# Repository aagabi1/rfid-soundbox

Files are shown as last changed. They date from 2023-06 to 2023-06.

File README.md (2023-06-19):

# rfid-soundbox
This is a modular prototype designed to mimick the famous gramophone using rfid technology - similar to the speaker system from the Ikea Frekvens collection (https://www.ikea.com/us/en/files/pdf/27/28/27281cda/frekvens_pr_kit.pdf).
Check out the rfid soundbox documentation pdf for a more detailed description.

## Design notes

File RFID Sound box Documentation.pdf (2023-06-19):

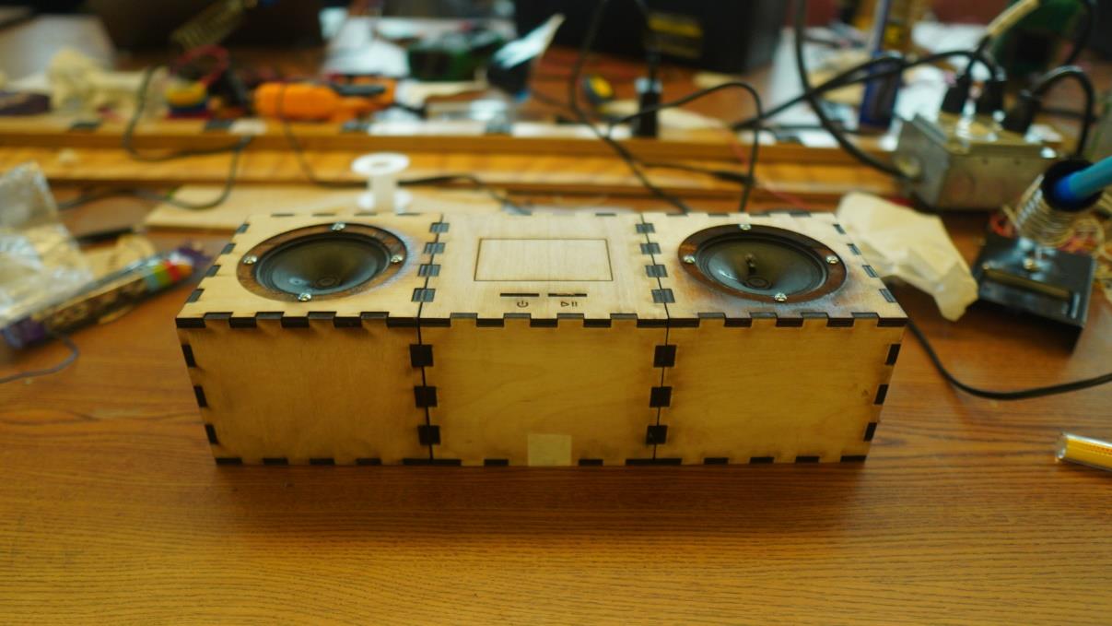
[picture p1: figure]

RFID Sound box Documentation

Courage Agabi

Section A

Part 1 – Hardware components

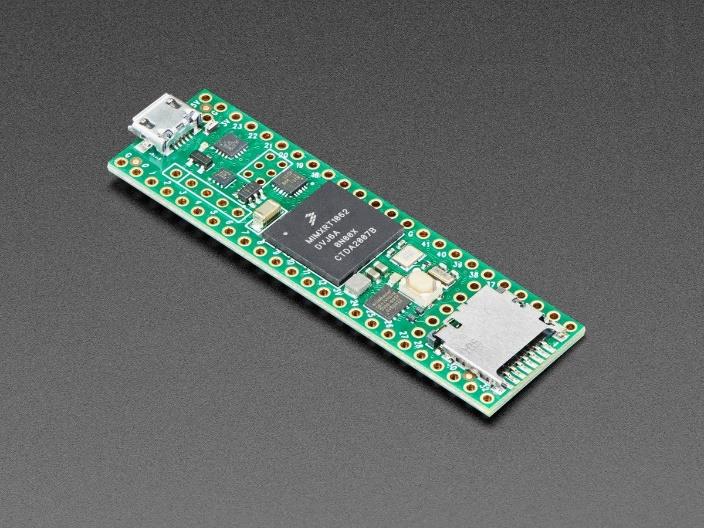
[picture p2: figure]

Teensy 4.1

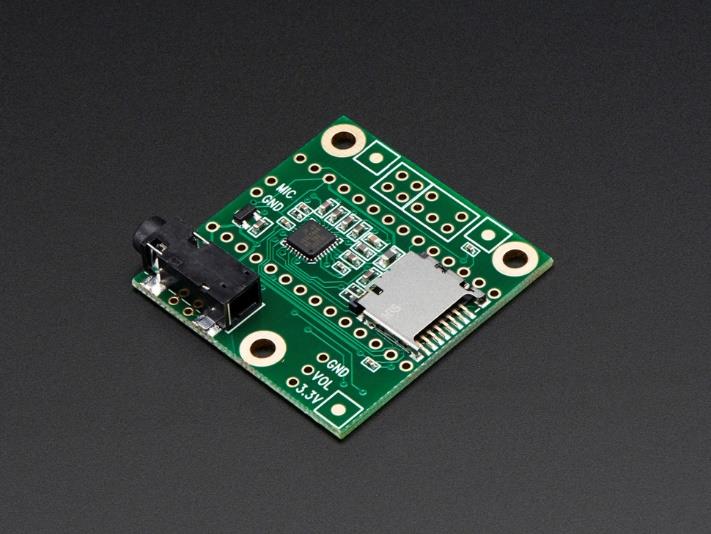
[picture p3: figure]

Teensy 16bit audio shield

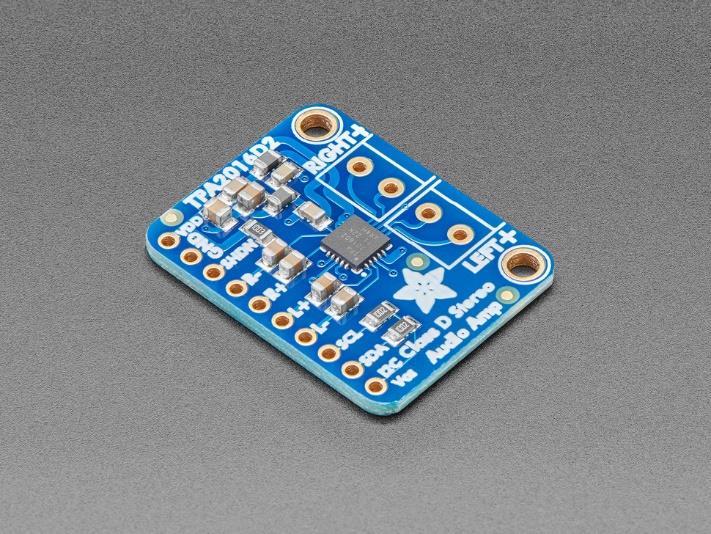
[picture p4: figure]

Adafruit 2.8W amplifier

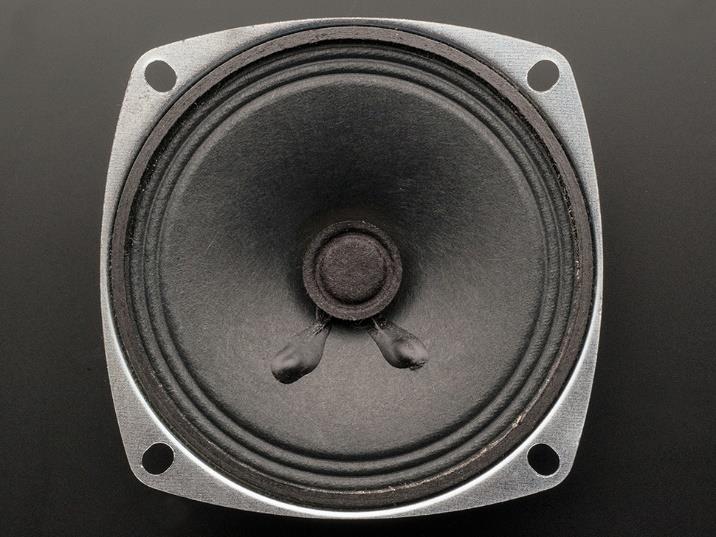
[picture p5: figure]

3W 4-ohm impedance speakers

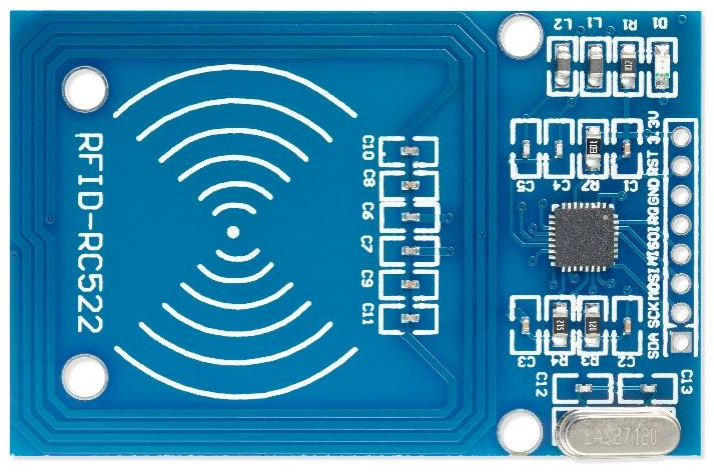
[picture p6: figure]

RFID reader

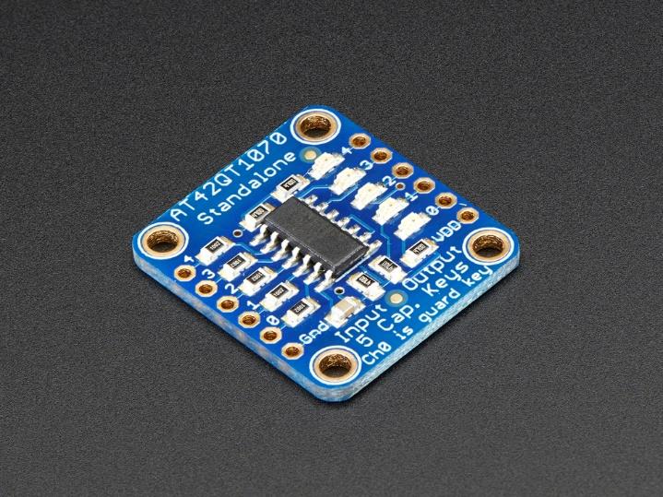
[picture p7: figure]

Capacitive touch sensor

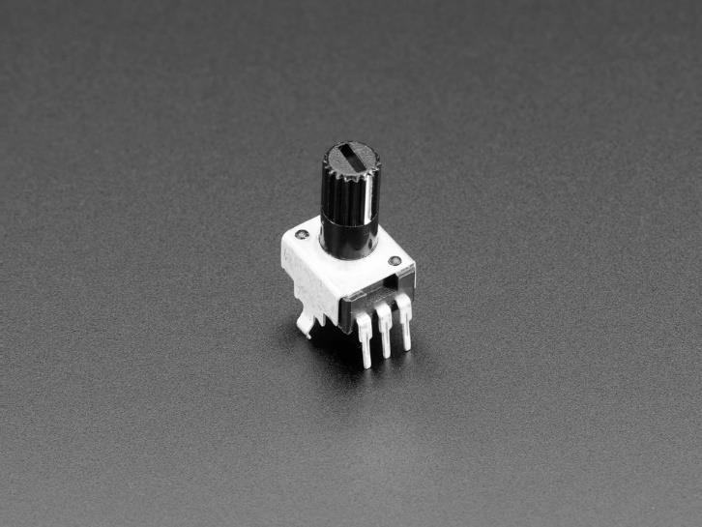
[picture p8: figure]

10k potentiometer

Part 2 – Libraries

MFRC512 library for RFID functionality (https://github.com/miguelbalboa/rfid.git)

TPA2016 for controlling amplifier (https://github.com/adafruit/Adafruit-TPA2016-Library.git)

Teensy audio library for controlling sgtl5000 chip in audio shield (https://www.pjrc.com/teensy/gui/)

Bounce library for touch input debouncing (https://github.com/thomasfredericks/Bounce2.git)

Wire library for I2C and SPI library for RFID reader

Part 3 – Custom components

RFID read and write

The MFRC library had functions to read and write hex values to a card but I needed to specify what part of the tag the data was written into and also add delimiters to know where to start and stop reading. I also needed to automatically convert the file name into hex and back into text when read. It would have been possible to do all this with the given functions but using this custom approach gave me a better understanding of the RFID tag system and how it can be used for projects that require higher encryption. It also helped with debugging read/write issues.

Audio amp node for volume control

The sgtl5000 chip allows you to change the voltage levels for the line out outputs. However, the result is a discrete step in volume change. I wanted continuous, smooth transitions in volume so I added an audio amplifier between the SD card wav node and the audio shield I2S node (see image below)

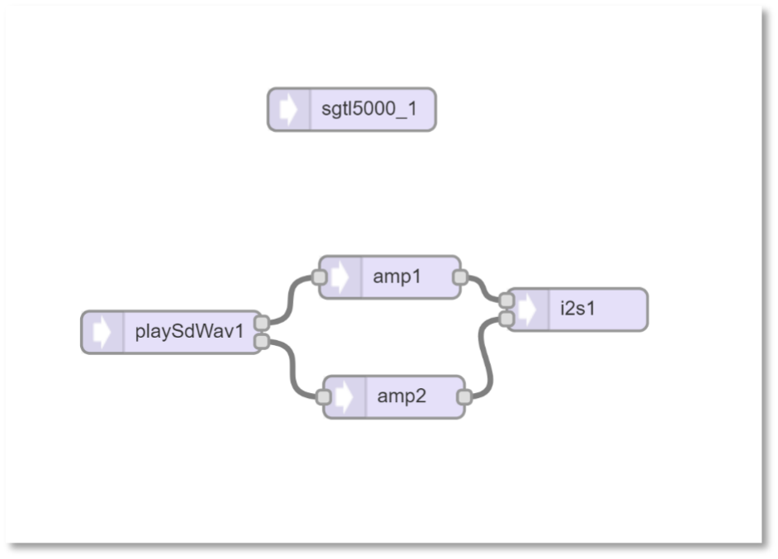
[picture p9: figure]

Figure 1. Sample audio configuration from PJRC graphic interface.

Hardware mounts

Finally, I designed hardware mounts for the audio shield, amplifier and power source. I did not want to glue these pieces to the plywood in case I needed them for other projects so I 3D printed these plates with side rails to hold the components. There are also notches on the side of the rails so that rubber bands can be wrapped around and placed in the notches. Lastly, the plates have extruding legs underneath that insert into holes in the plywood.

Part 4 – Skill learned

RFID data manipulation

I learned more about RFID tags than I care to admit. I learned potential ways to create more secure RFID tags such that it would be a reliable option for a household door locking system. Basically, you can change the key that the RFID tags have by default. The key is what you need to read data off the card. All tags have a default key but if you have a custom key it would be harder to use any key to open a door lock. And combined with the actual data on the key, the number of possible combinations increases exponentially (although there are still ways to get around this if you have unrestricted access to a person’s key).

3D printing best practices

I learned that when trying to fit or mount 3D printed pieces together, it is best to make more generic designs rather that hyper specific designs since the degree of accuracy of the 3D print is not always perfect. So, rather than have prongs sticking out from a 3D printed plate that fit specific mounting holes on a circuit board, you can just print rails that hold on to the board from the sides.

Part 5 – Iterative process

There were many moving parts in the assignment, so I worked on incremental features…

1. Getting the RFID to read and write the file name – this was fairly easy given that there is existing code to do this. I just had to understand where the data was being written and in what format
2. Getting the audio shield to play the song – this was a bit more difficult because of a few unknown bugs. The filename had to be in 8.3 format (excluding the directory) and it had to be all capital letters. So, for a song like “Stevie Wonder – Sir Duke” in the folder called “Stevie”, the data on the tag would be “STEVIE/SIRDUKE.WAV”. It was little things like this that made play back hard at first.
3. Once the tag had the right file format and the audio shield could read that file from the SD card, then the audio would play from the headphone jack
4. Getting the touch input – the capacitive touch sensor was also tricky because unbeknownst to me, it did some super quick calibration when power was turned on so the range would differ every time. However, getting it to work was straightforward with the Bounce library. The audio shield also had an updated play and pause method that was added recently so that made playback control easier.
5. Finally, I had to get the amp and speakers connected. The issue was with the wiring of the amp and potential ground loop which cause a lot of noise in the music. I fixed this issue by giving the amp and independent ground reference from the rest of the components (audio shield LR outputs and ground connections). Also, the design of the speakers was modular so the amp would struggle with properly powering the speakers if they were attached at different times. I have not found a fix or done enough testing to figure this part out

Ideas that didn’t pan out…

1. Connecting to Spotify – the audio amplifier issue was such a big problem for me that I was more focused on getting the best sound out of the speakers before adding the extra functionality. Also, the internet requirement would have meant that I had to buy another board (ESP-32) to connect the Teensy to Wi-Fi which would have been more expensive
2. Adjusting playback – I wanted to be able to rewind a song or just have all the songs play on shuffle but there was no straightforward way to adjust playback and I didn’t have time to implement the latter
3. Low power mode – The teensy has an option for low power mode where it basically shuts off when you connect the power ON/OFF pin to ground. I wanted to implement this with a transistor such that current flowed when the capacitive touch input drove the base high. I wasn’t sure if this would work and I didn’t want to try anything that might damage the Teensy so I just manually shut down the power supply.

Part 6 – Lessons learned

1. The most important lesson is probably that when working with audio, you have to make sure that you ground pins are properly connected to avoid audible noise problems. I thing a soldering solution would have been better and I think I should have started with just the amplifier and speaker and the DAC on the teensy before introducing the audio shield and the multiple ground connections.
2. When 3D printing, leave room for error and design more generally so that all the measurements don’t have to be ultra-specific for the piece to fit

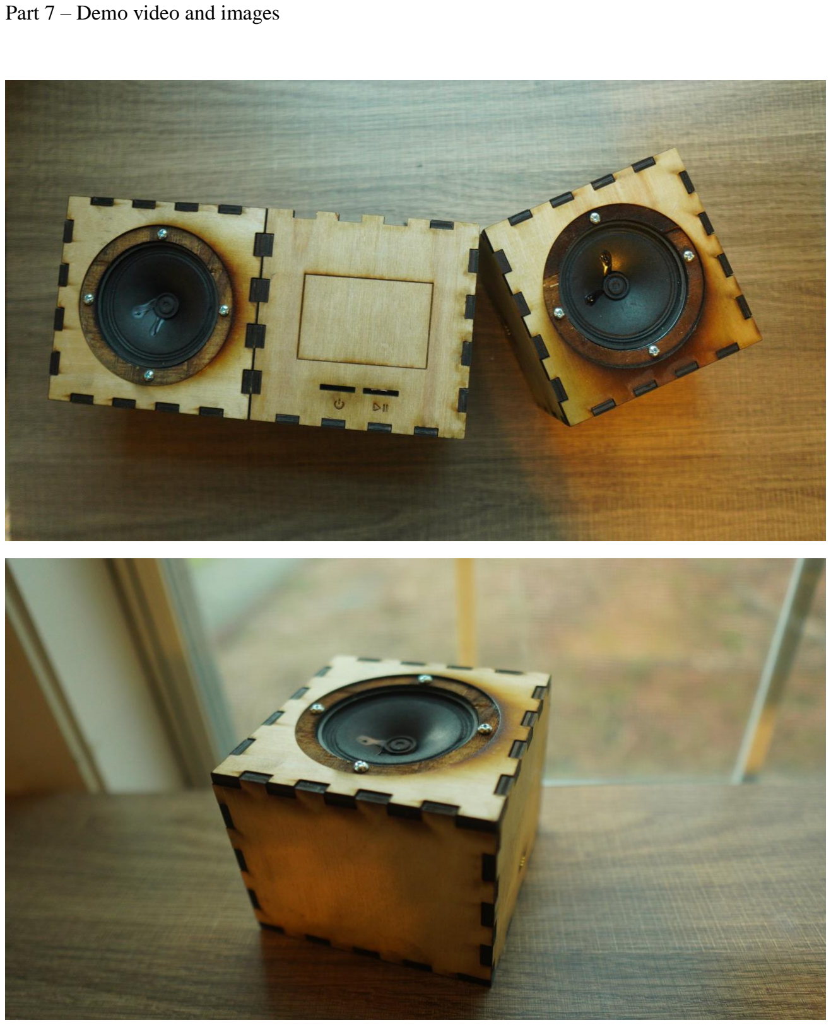
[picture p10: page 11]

Part 7 – Demo video and images

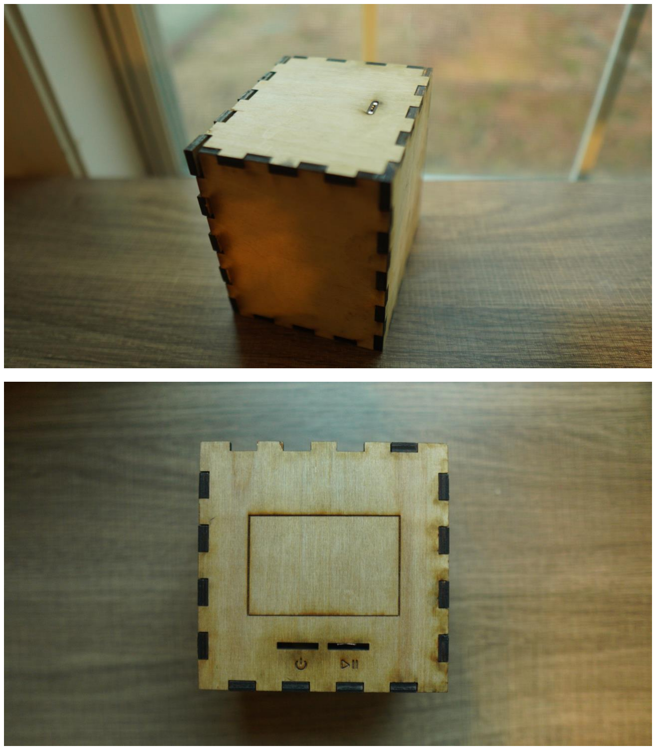
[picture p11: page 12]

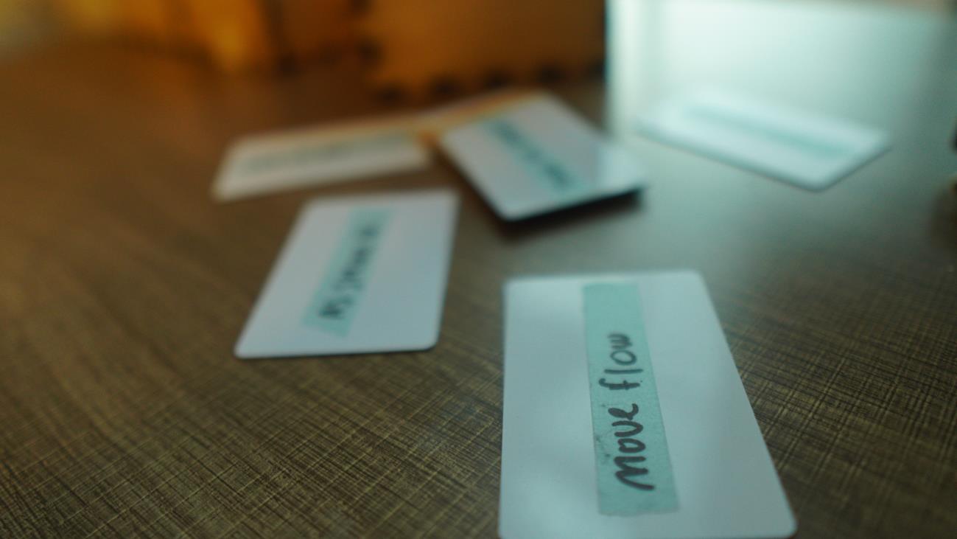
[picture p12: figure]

** see zip file for demo video

Part 8 – Code

**check zip folder for .cpp files (under the src folder)

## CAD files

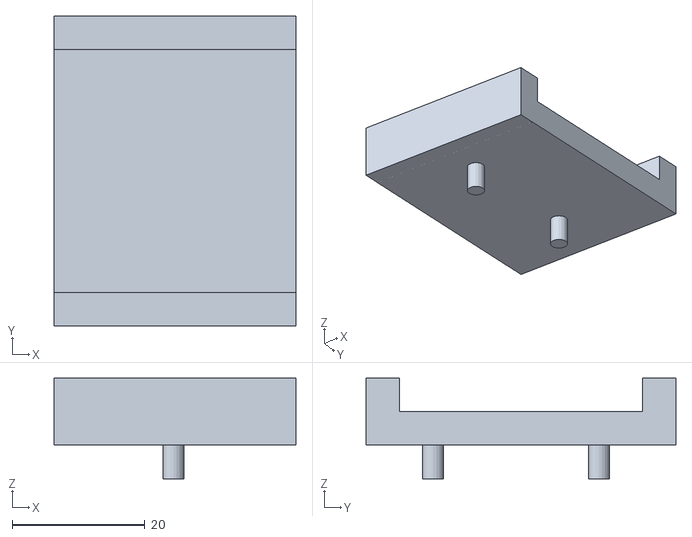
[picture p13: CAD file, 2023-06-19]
build/audio_shield.stl
36.5 x 46.7 x 15.2

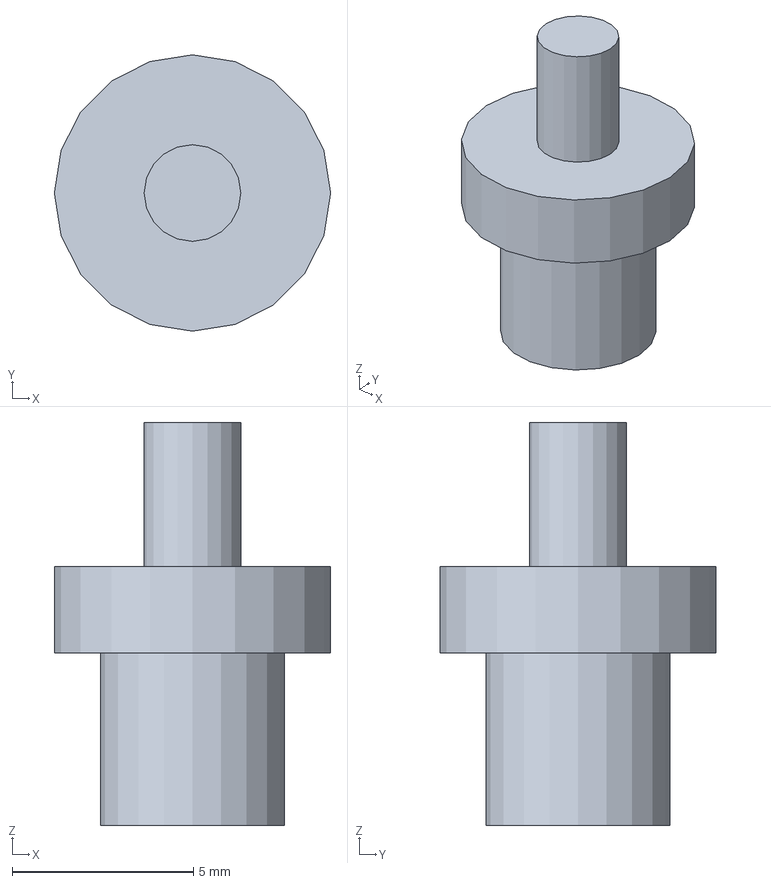
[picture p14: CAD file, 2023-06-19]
build/raw/MSMV1_clip_bottom.3mf
7.62 x 7.62 x 11.1 mm

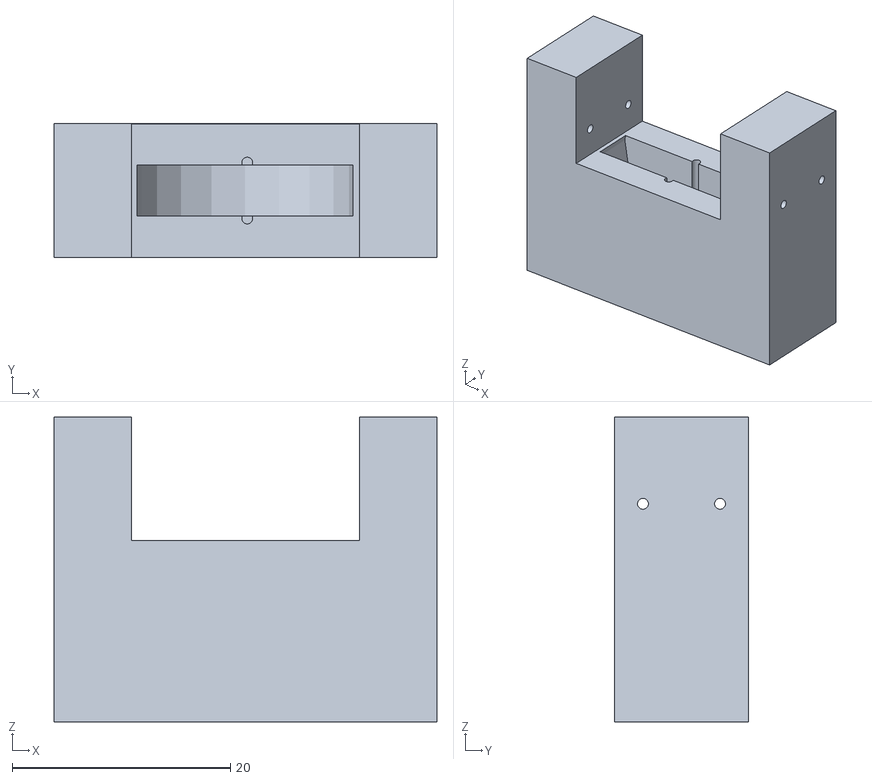
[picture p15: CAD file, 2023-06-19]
build/cell_battery.stl
35.1 x 12.3 x 28.0

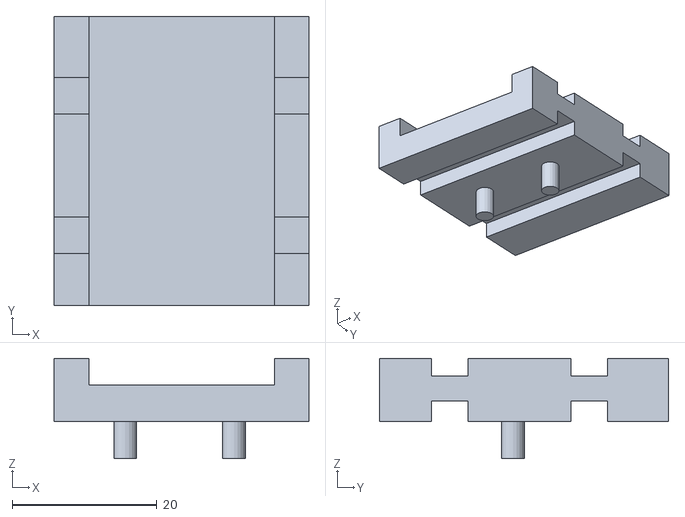
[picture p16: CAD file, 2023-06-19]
build/lipo final.stl
35.2 x 40.0 x 13.8

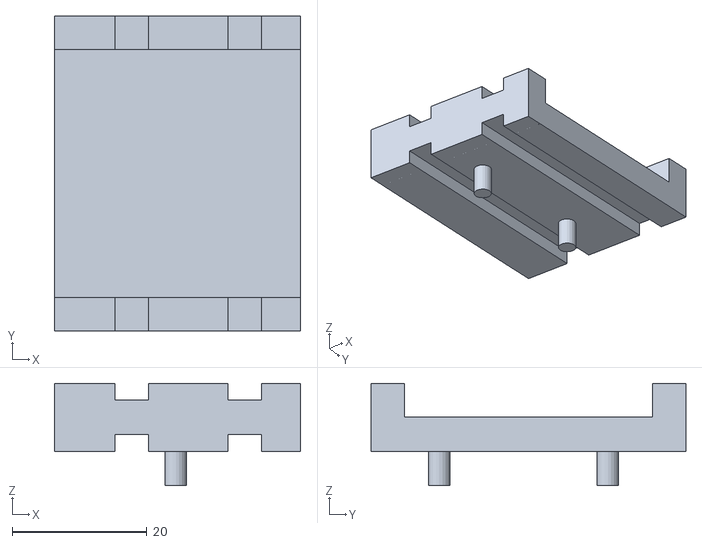
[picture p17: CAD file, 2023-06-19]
build/audio_shield2.stl
36.5 x 46.7 x 15.2

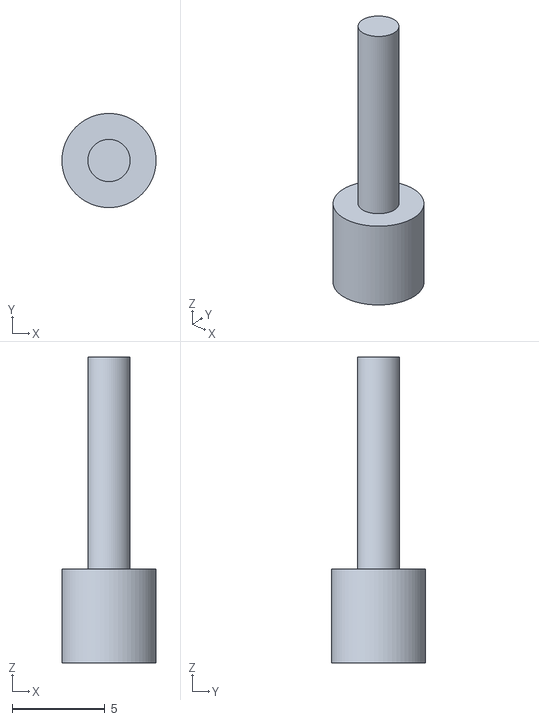
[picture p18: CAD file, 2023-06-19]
build/clip_bottom.stl
5.08 x 5.08 x 16.5

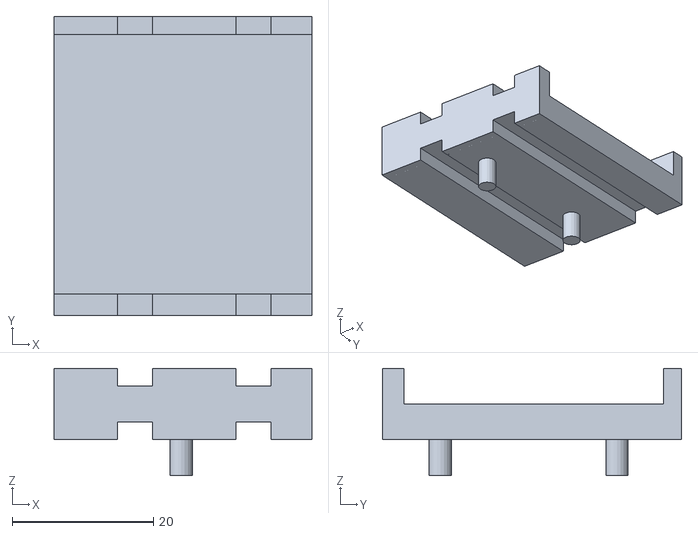
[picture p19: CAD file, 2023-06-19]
build/audio_shield3.stl
36.5 x 42.3 x 15.2

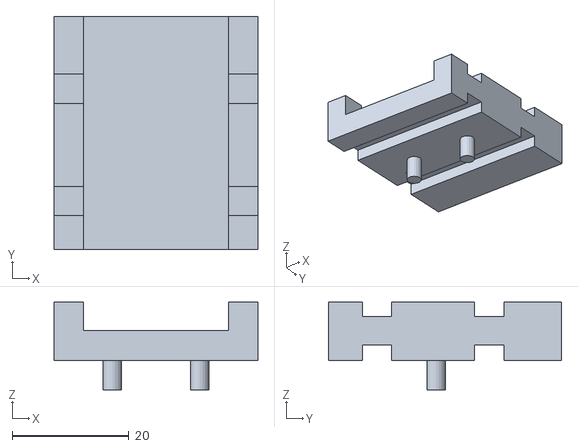
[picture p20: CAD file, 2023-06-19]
build/lipo_rider.stl
35.0 x 40.0 x 15.1

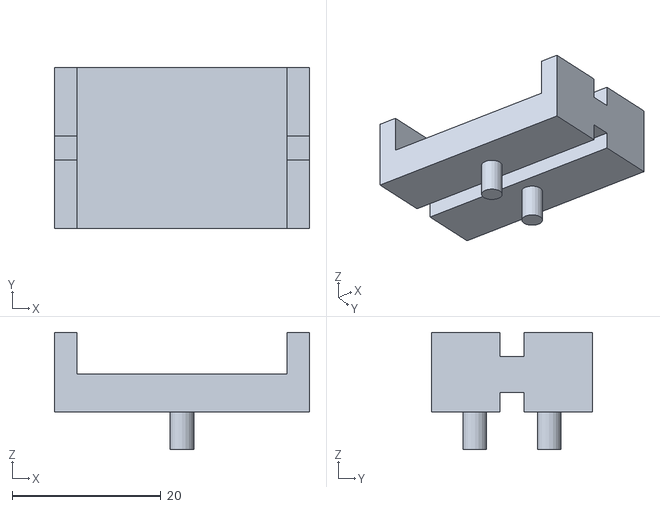
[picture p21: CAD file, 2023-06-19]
build/amp.stl
34.3 x 21.6 x 15.8

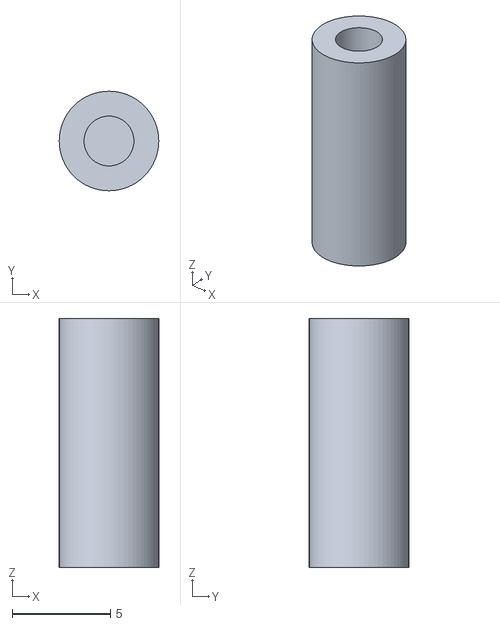
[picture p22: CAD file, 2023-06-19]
build/clip_top.stl
5.08 x 5.08 x 12.7

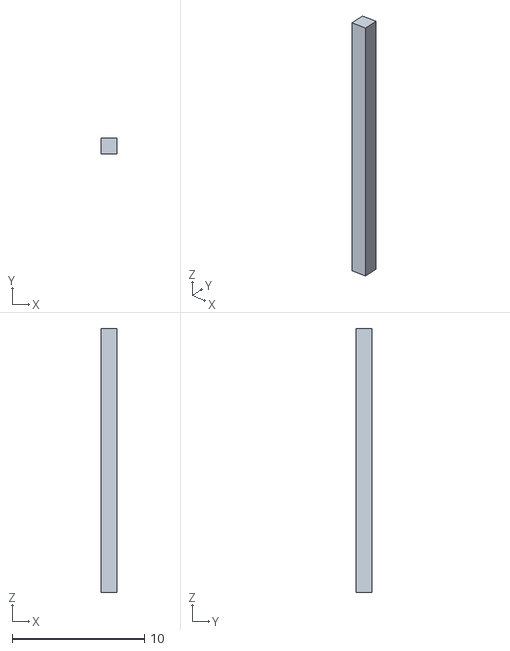
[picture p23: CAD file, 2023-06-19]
build/filler.stl
1.20 x 1.20 x 20.0

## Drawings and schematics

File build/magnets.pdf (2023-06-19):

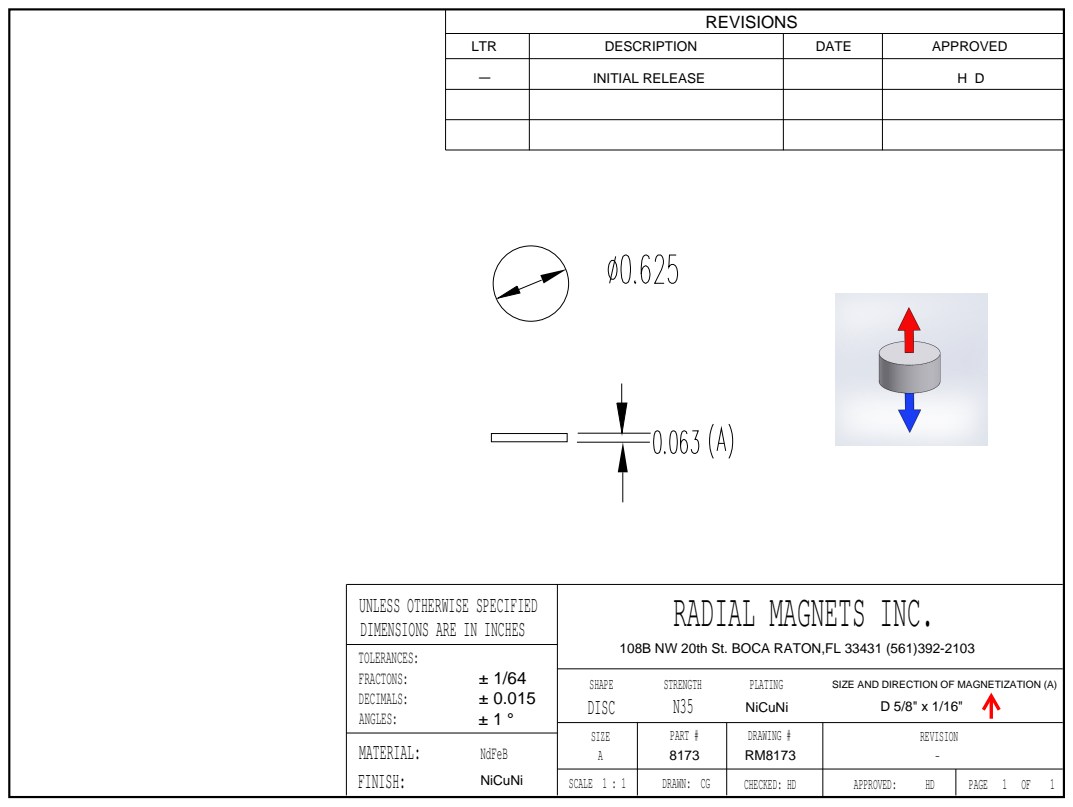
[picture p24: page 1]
NdFeB; NiCuNi; DRAWING # RM8173; PART # 8173; REVISION; MATERIAL:; FINISH:; SHAPE DISC; SIZE; SCALE 1 : 1; PAGE; FRACTONS:; DECIMALS:; ANGLES:; TOLERANCES:; DIMENSIONS ARE IN INCHES; RADIAL MAGNETS INC.; STRENGTH; PLATING; DRAWN: CG; CHECKED: HD; APPROVED:; REVISIONS; LTR; DESCRIPTION; DATE; APPROVED; INITIAL RELEASE

UNLESS OTHERWISE SPECIFIED

108B NW 20th St. BOCA RATON,FL 33431 (561)392-2103

SIZE AND DIRECTION OF MAGNETIZATION (A)

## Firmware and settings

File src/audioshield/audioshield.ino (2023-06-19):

/**
 * Simple WAV file player.
 */
#include <Audio.h>
#include <Wire.h>
#include <SPI.h>
#include <SD.h>
#include <SerialFlash.h>

// Use these with the Teensy Audio Shield
#define SDCARD_CS_PIN    10
#define SDCARD_MOSI_PIN  11
#define SDCARD_SCK_PIN   13

/**
 * Function declarations.
 */
void playFile(const char *filename);

AudioPlaySdWav           playSdWav;
AudioOutputI2S           audioOutput;
AudioConnection          patchCord1(playSdWav, 0, audioOutput, 0);
AudioConnection          patchCord2(playSdWav, 1, audioOutput, 1);
AudioControlSGTL5000     sgtl5000_1;


void setup() {
  Serial.begin(9600);

  // Audio connections require memory to work.  For more
  // detailed information, see the MemoryAndCpuUsage example
  AudioMemory(8);

  sgtl5000_1.enable();
  sgtl5000_1.volume(0.8);

  SPI.setMOSI(SDCARD_MOSI_PIN);
  SPI.setSCK(SDCARD_SCK_PIN);
  if (!(SD.begin(SDCARD_CS_PIN))) {
    // stop here, but print a message repetitively
    while (1) {
      Serial.println("Unable to access the SD card");
      delay(500);
    }
  }
}

void loop() {
  playFile("STEVIE/ASSTEV.WAV");  // filenames are always uppercase 8.3 format
  delay(500);
}

void playFile(const char *filename)
{
  Serial.print("Playing file: ");
  Serial.println(filename);

  // Start playing the file.  This sketch continues to
  // run while the file plays.
  playSdWav.play(filename);

  // A brief delay for the library read WAV info
  delay(25);

  // Simply wait for the file to finish playing.
  while (playSdWav.isPlaying()) {
    // uncomment these lines if you audio shield
    // has the optional volume pot soldered
    //float vol = analogRead(15);
    //vol = vol / 1024;
    // sgtl5000_1.volume(vol);
  }
}

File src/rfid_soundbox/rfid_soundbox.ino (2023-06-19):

/**
 * ----------------------------------------------------------------------------
 * This is the base program for the rfid sound-box project.
 * 
 */

#include "mfrc522_singleton.h"
#include "audioshield_singleton.h"
using namespace std;

/**
 * external variables.
 */
bool ISR_IsNewCardPresent;
string currentSong {};
string lastSong {};
string cardData {};

/**
 * Initialize.
 */
void setup() {
  Serial.begin(9600);               // Initialize serial communications with the PC
  delay(2000);
  Serial.println("LOADING>>>");

  audioshield_setup();
  mfrc_setup();

  ISR_IsNewCardPresent = false;
  currentSong = "IDLE";
}

/**
 * Main loop.
 */
void loop() {
  if (!ISR_IsNewCardPresent) {
    ISR_IsNewCardPresent = false;
    
    // Look for new cards
    if ( ! mfrc522.PICC_IsNewCardPresent())
        return;
  
    // Select one of the cards
    if ( ! mfrc522.PICC_ReadCardSerial())
        return;

    cardData = parsePICCMemory();

    // Halt PICC
    mfrc522.PICC_HaltA();
    // Stop encryption on PCD
    mfrc522.PCD_StopCrypto1();

    lastSong = currentSong;
    currentSong = cardData;

    // Check if valid
    if ( cardData.size() == 0)
      return;
  }

  string songTitle = currentSong;
  Serial.println(&songTitle[0]);
  
  // Play song
  playFile(&songTitle[0]);
  delay(500);
}
